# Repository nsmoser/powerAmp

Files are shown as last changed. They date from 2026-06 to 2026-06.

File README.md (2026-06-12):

Audio amplifier project implementing the LM3886 audio power amplifier.
Originally intended to replace a busted board in a powered subwoofer, but designed to be reused as a L/R stereo amp.
NOTE: the mute circuit was incorrectly connected to ground instead of the negative rail. Current draw necessary to unmute cannot be achieved unless the switch is connected to the negative rail.
Realistically, not all three matching pairs of caps in the cap bank are necessary. Connect the mute switch to one of the negative rail through holes in the cap bank if the bank isn't fully populated.
The low voltage power components are also not necessary for function. They are there to power peripherals (indicator lights, add-on pre-filters or pre-amps, etc.)

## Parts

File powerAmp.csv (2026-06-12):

Reference | Qty | Value | DNP | Exclude from BOM | Exclude from Board | Footprint | Datasheet | PN
C1,C2 | 2 | 4.7u |  |  |  | Capacitor_SMD:C_0805_2012Metric | ~ | GRM21BZ71H475ME15K
C3,C4,C9,C12 | 4 | 0.1u |  |  |  | Capacitor_SMD:C_1206_3216Metric | ~ | CL31B104KEHSFNE
C5,C6,C7,C8,C10,C11 | 6 | 10000u |  |  |  | Capacitor_THT:CP_Radial_D35.0mm_P10.00mm_SnapIn | ~ | EKMH500VSN103MA40U
C13 | 1 | .1u |  |  |  | Capacitor_SMD:C_0402_1005Metric | ~ | GCM155R71H104KE02J
C14,C15 | 2 | 10u |  |  |  | Capacitor_SMD:CP_Elec_5x5.3 | ~ | UCD1H100MCL6GS
D1,D2 | 2 | GBU8B |  |  |  | Diode_THT:Diode_Bridge_Vishay_GBU | http://www.vishay.com/docs/88656/gbu8a.pdf | GBU8B
D3 | 1 | LED |  |  |  | Connector_PinSocket_2.54mm:PinSocket_1x02_P2.54mm_Vertical | ~
FL1,FL2 | 2 | Choke_Schaffner_RN102-2-02-1M1 |  |  |  | Inductor_THT:Choke_Schaffner_RN102-04-14.0x14.0mm | https://www.schaffner.com/products/download/product/datasheet/rn-series-common-mode-chokes-new/ | RN102-2-02-1M1
H1,H2,H3,H4 | 4 | MountingHole_Pad |  | Excluded from BOM |  | MountingHole:MountingHole_4.3mm_M4_Pad_TopBottom | ~
J1 | 1 | Conn_Coaxial_x2 |  |  |  | Connector_PinSocket_2.54mm:PinSocket_1x03_P2.54mm_Vertical | ~
J2 | 1 | Conn_01x05 |  |  |  | Connector_PinSocket_2.54mm:PinSocket_1x05_P2.54mm_Vertical | ~
J3 | 1 | Conn_01x02_Pin |  |  |  | Connector_PinSocket_2.54mm:PinSocket_1x02_P2.54mm_Vertical | ~
J4,J5,J6,J7 | 4 | Conn_01x01_Socket |  |  |  | Connector_PinSocket_2.54mm:PinSocket_1x01_P2.54mm_Vertical | ~
R1,R2 | 2 | 1M |  |  |  | Resistor_SMD:R_2512_6332Metric | ~ | CHV2512-FX-1004ELF
R3 | 1 | 1500 |  |  |  | Resistor_SMD:R_0603_1608Metric | ~ | CRCW06031K50FKEAC
RV1,RV2 | 2 | levelCal |  |  |  | Potentiometer_THT:Potentiometer_Bourns_3009P_Horizontal | ~ | 3009P-1-104LF
RV3,RV4 | 2 | volAdjust |  |  |  | Connector_PinSocket_2.54mm:PinSocket_1x03_P2.54mm_Vertical | ~ | PDB181-E420F-103B1
SW1 | 1 | SW_SPST |  |  |  | Connector_PinSocket_2.54mm:PinSocket_1x02_P2.54mm_Vertical | ~
TP1 | 1 | in_preCal_L |  |  |  | TestPoint:TestPoint_Pad_1.0x1.0mm | ~
TP2 | 1 | in_preCal_R |  |  |  | TestPoint:TestPoint_Pad_1.0x1.0mm | ~
TP3 | 1 | in_postCal_L+ |  |  |  | Connector_PinHeader_2.54mm:PinHeader_1x01_P2.54mm_Vertical | ~
TP4 | 1 | in_postCal_R+ |  |  |  | Connector_PinHeader_2.54mm:PinHeader_1x01_P2.54mm_Vertical | ~
TP5 | 1 | in_postCal_L- |  |  |  | Connector_PinHeader_2.54mm:PinHeader_1x01_P2.54mm_Vertical | ~
TP6 | 1 | in_postCal_R- |  |  |  | Connector_PinHeader_2.54mm:PinHeader_1x01_P2.54mm_Vertical | ~
TP7 | 1 | dc- |  |  |  | TestPoint:TestPoint_Pad_1.0x1.0mm | ~
TP8 | 1 | gnd |  |  |  | TestPoint:TestPoint_Pad_1.0x1.0mm | ~
TP9 | 1 | dc+ |  |  |  | TestPoint:TestPoint_Pad_1.0x1.0mm | ~
TP10 | 1 | amp_in_L |  |  |  | Connector_PinHeader_2.54mm:PinHeader_1x01_P2.54mm_Vertical | ~
TP11 | 1 | amp_in_R |  |  |  | Connector_PinHeader_2.54mm:PinHeader_1x01_P2.54mm_Vertical | ~
U1 | 1 | LM7812_TO220 |  |  |  | Package_TO_SOT_THT:TO-220-3_Vertical | https://www.onsemi.cn/PowerSolutions/document/MC7800-D.PDF

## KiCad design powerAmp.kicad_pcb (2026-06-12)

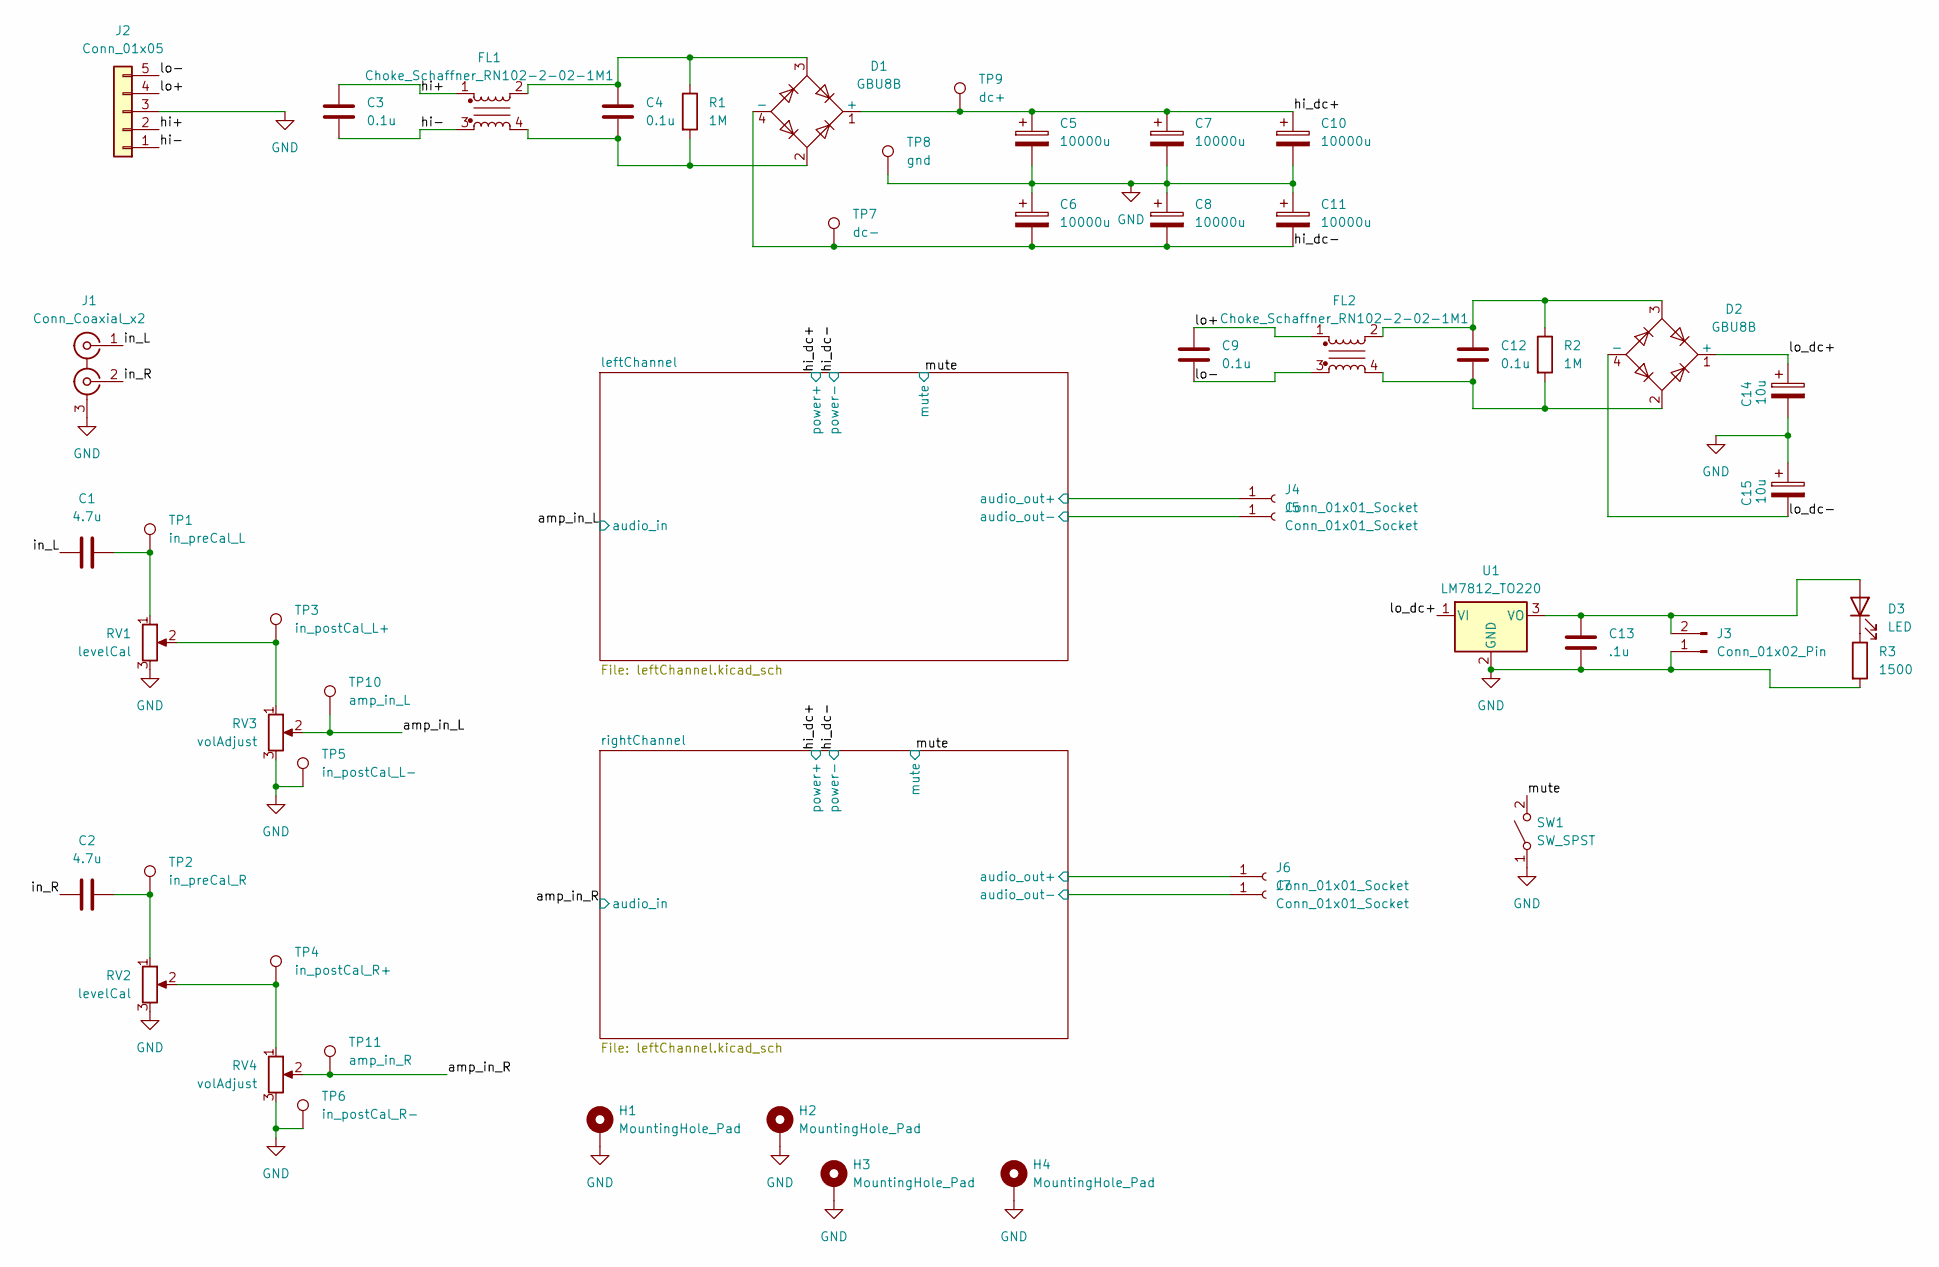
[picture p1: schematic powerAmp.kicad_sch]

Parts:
C1, C2: 4.7u; C_0805_2012Metric
C3, C4, C9, C12: 0.1u; C_1206_3216Metric
C5, C6, C7, C8, C10, C11: 10000u; CP_Radial_D35.0mm_P10.00mm_SnapIn
C13: .1u; C_0402_1005Metric
C14, C15: 10u; CP_Elec_5x5.3
D1, D2: GBU8B; Diode_Bridge_Vishay_GBU
D3: LED; PinSocket_1x02_P2.54mm_Vertical
FL1, FL2: Choke_Schaffner_RN102-2-02-1M1; Choke_Schaffner_RN102-04-14.0x14.0mm
H1, H2, H3, H4: MountingHole_Pad; MountingHole_4.3mm_M4_Pad_TopBottom
J1: Conn_Coaxial_x2; PinSocket_1x03_P2.54mm_Vertical
J2: Conn_01x05; PinSocket_1x05_P2.54mm_Vertical
J3: Conn_01x02_Pin; PinSocket_1x02_P2.54mm_Vertical
J4, J5, J6, J7: Conn_01x01_Socket; PinSocket_1x01_P2.54mm_Vertical
R1, R2: 1M; R_2512_6332Metric
R3: 1500; R_0603_1608Metric
RV1, RV2: levelCal; Potentiometer_Bourns_3009P_Horizontal
RV3, RV4: volAdjust; PinSocket_1x03_P2.54mm_Vertical
SW1: SW_SPST; PinSocket_1x02_P2.54mm_Vertical
TP1: in_preCal_L; TestPoint_Pad_1.0x1.0mm
TP2: in_preCal_R; TestPoint_Pad_1.0x1.0mm
TP3: in_postCal_L+; PinHeader_1x01_P2.54mm_Vertical
TP4: in_postCal_R+; PinHeader_1x01_P2.54mm_Vertical
TP5: in_postCal_L-; PinHeader_1x01_P2.54mm_Vertical
TP6: in_postCal_R-; PinHeader_1x01_P2.54mm_Vertical
TP7: dc-; TestPoint_Pad_1.0x1.0mm
TP8: gnd; TestPoint_Pad_1.0x1.0mm
TP9: dc+; TestPoint_Pad_1.0x1.0mm
TP10: amp_in_L; PinHeader_1x01_P2.54mm_Vertical
TP11: amp_in_R; PinHeader_1x01_P2.54mm_Vertical
U1: LM7812_TO220; TO-220-3_Vertical

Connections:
/amp_in_L: RV3.2, TP10.1; also elsewhere on the board
/amp_in_R: RV4.2, TP11.1; also elsewhere on the board
/hi+: C3.1, FL1.1, J2.2
/hi-: C3.2, FL1.3, J2.1
/hi_dc+: C5.1, C7.1, C10.1, D1.1 (+), TP9.1; also elsewhere on the board
/hi_dc-: C6.2, C8.2, C11.2, D1.4 (-), TP7.1; also elsewhere on the board
/in_L: C1.1, J1.1 (IN1)
/in_R: C2.1, J1.2 (IN2)
/leftChannel/audio_out+: J4.1; also elsewhere on the board
/leftChannel/audio_out-: J5.1; also elsewhere on the board
/lo+: C9.1, FL2.1, J2.4
/lo-: C9.2, FL2.3, J2.5
/lo_dc+: C14.1, D2.1 (+), U1.1 (VI)
/lo_dc-: C15.2, D2.4 (-)
/mute: SW1.2 (B); also elsewhere on the board
/rightChannel/audio_out+: J6.1; also elsewhere on the board
/rightChannel/audio_out-: J7.1; also elsewhere on the board
GND: C5.2, C6.1, C7.2, C8.1, C10.2, C11.1, C13.1, C14.2, C15.1, H1.1, H2.1, H3.1, H4.1, J1.3 (EXT), J2.3, J3.1, R3.2, RV1.3, RV2.3, RV3.3, RV4.3, SW1.1 (A), TP5.1, TP6.1, TP8.1, U1.2 (GND); also elsewhere on the board
unnamed: C1.2, RV1.1, TP1.1
unnamed: C2.2, RV2.1, TP2.1
unnamed: C4.1, D1.3, FL1.2, R1.1
unnamed: C4.2, D1.2, FL1.4, R1.2
unnamed: C12.1, D2.3, FL2.2, R2.1
unnamed: C12.2, D2.2, FL2.4, R2.2
unnamed: C13.2, D3.2 (A), J3.2, U1.3 (VO)
unnamed: D3.1 (K), R3.1
unnamed: RV1.2, RV3.1, TP3.1
unnamed: RV2.2, RV4.1, TP4.1

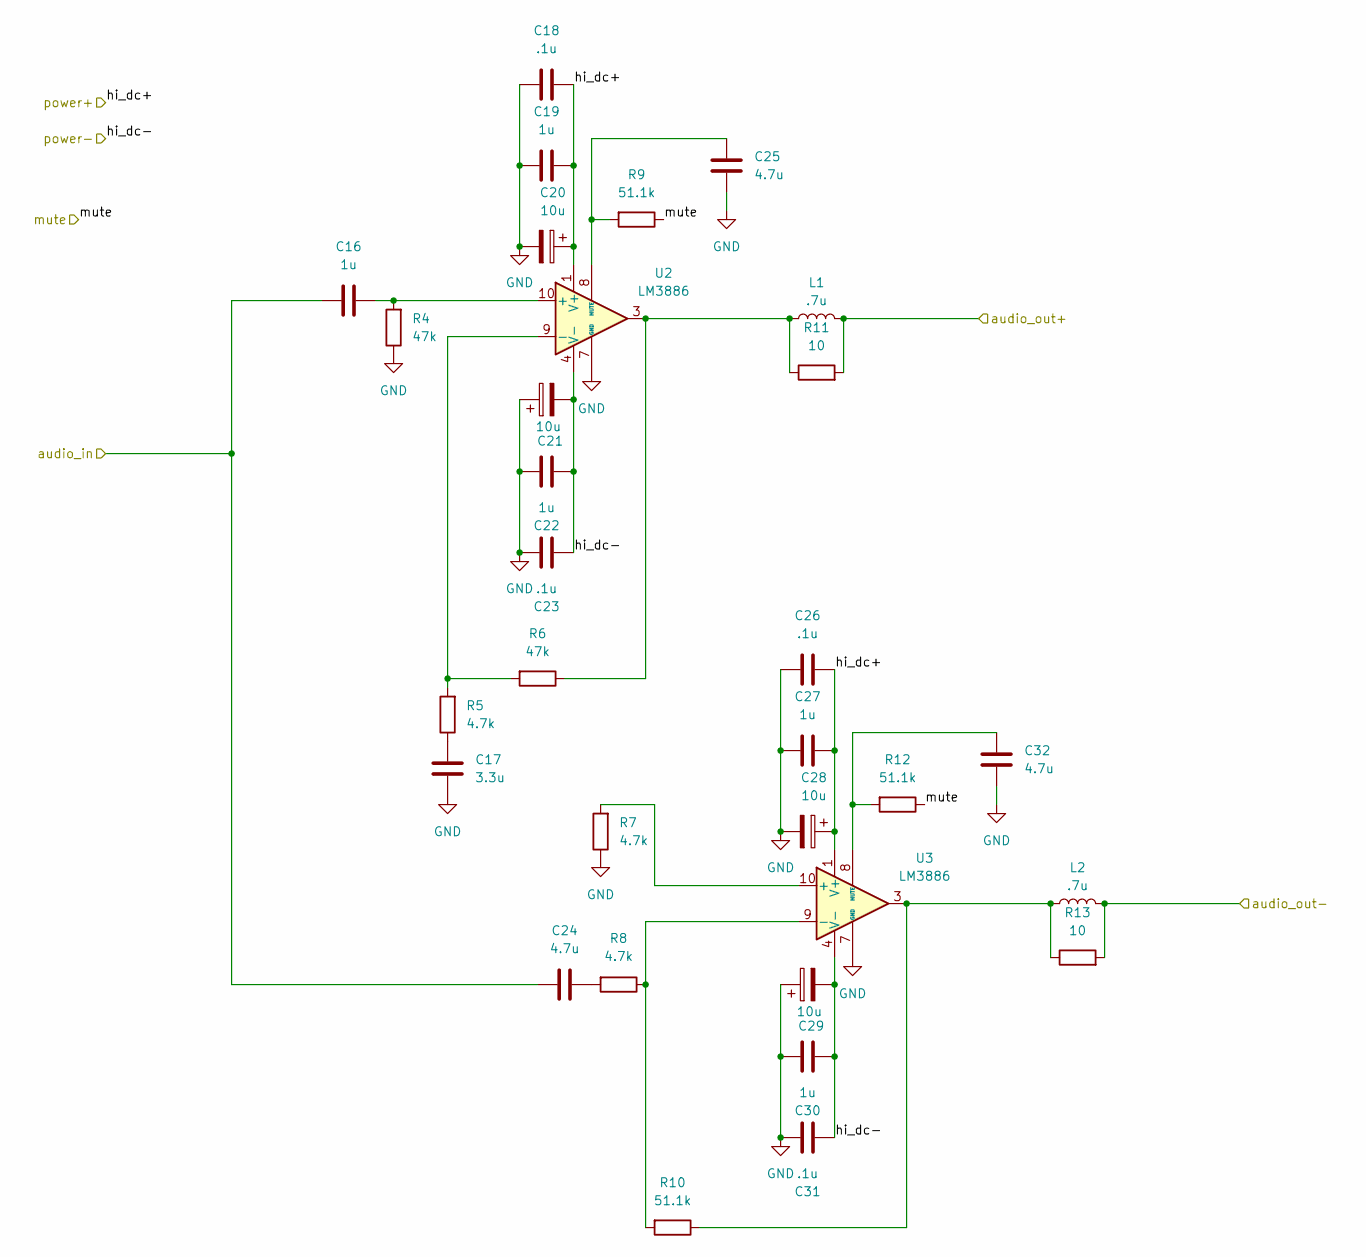
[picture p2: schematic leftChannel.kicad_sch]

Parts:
C16, C19, C22, C27, C30: 1u; C_0805_2012Metric
C17: 3.3u; C_1210_3225Metric
C18, C23, C26, C31: .1u; C_0402_1005Metric
C20, C21, C28, C29: 10u; CP_Elec_5x5.3
C24, C25, C32: 4.7u; C_0805_2012Metric
L1, L2: .7u; L_Vishay_IHLP-1616
R4, R6: 47k; R_0603_1608Metric
R5, R7, R8: 4.7k; R_0603_1608Metric
R9, R10, R12: 51.1k; R_0603_1608Metric
R11, R13: 10; PinSocket_1x02_P2.54mm_Vertical
U2, U3: LM3886; TO-220F-11_P3.4x5.08mm_StaggerOdd_Lead5.08mm_Vertical

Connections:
/amp_in_L: C16.1, C24.1; also elsewhere on the board
/hi_dc+: C18.2, C19.2, C20.1, C26.2, C27.2, C28.1, U2.1 (V+), U2.5 (V+), U3.1 (V+), U3.5 (V+); also elsewhere on the board
/hi_dc-: C21.2, C22.1, C23.1, C29.2, C30.1, C31.1, U2.4 (V-), U3.4 (V-); also elsewhere on the board
/leftChannel/audio_out+: L1.2, R11.2; also elsewhere on the board
/leftChannel/audio_out-: L2.2, R13.2; also elsewhere on the board
/mute: R9.1, R12.1; also elsewhere on the board
GND: C17.1, C18.1, C19.1, C20.2, C21.1, C22.2, C23.2, C25.1, C26.1, C27.1, C28.2, C29.1, C30.2, C31.2, C32.1, R4.1, R7.1, U2.7 (GND), U3.7 (GND); also elsewhere on the board
unnamed: C17.2, R5.1
unnamed: C24.2, R8.2
unnamed: L1.1, R6.1, R11.1, U2.3
unnamed: L2.1, R10.1, R13.1, U3.3
unnamed: C16.2, R4.2, U2.10 (+)
unnamed: R5.2, R6.2, U2.9 (-)
unnamed: C25.2, R9.2, U2.8 (MUTE)
unnamed: R7.2, U3.10 (+)
unnamed: R8.1, R10.2, U3.9 (-)
unnamed: C32.2, R12.2, U3.8 (MUTE)

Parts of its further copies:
C33, C36, C39, C44, C47: 1u; C_0805_2012Metric
C34: 3.3u; C_1210_3225Metric
C35, C40, C43, C48: .1u; C_0402_1005Metric
C37, C38, C45, C46: 10u; CP_Elec_5x5.3
C41, C42, C49: 4.7u; C_0805_2012Metric
L3, L4: .7u; L_Vishay_IHLP-1616
R14, R16: 47k; R_0603_1608Metric
R15, R17, R18: 4.7k; R_0603_1608Metric
R19, R20, R22: 51.1k; R_0603_1608Metric
R21, R23: 10; PinSocket_1x02_P2.54mm_Vertical
U4, U5: LM3886; TO-220F-11_P3.4x5.08mm_StaggerOdd_Lead5.08mm_Vertical

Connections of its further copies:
/amp_in_R: C33.1, C41.1; also elsewhere on the board
/hi_dc+: C35.2, C36.2, C37.1, C43.2, C44.2, C45.1, U4.1 (V+), U4.5 (V+), U5.1 (V+), U5.5 (V+); also elsewhere on the board
/hi_dc-: C38.2, C39.1, C40.1, C46.2, C47.1, C48.1, U4.4 (V-), U5.4 (V-); also elsewhere on the board
/mute: R19.1, R22.1; also elsewhere on the board
/rightChannel/audio_out+: L3.2, R21.2; also elsewhere on the board
/rightChannel/audio_out-: L4.2, R23.2; also elsewhere on the board
GND: C34.1, C35.1, C36.1, C37.2, C38.1, C39.2, C40.2, C42.1, C43.1, C44.1, C45.2, C46.1, C47.2, C48.2, C49.1, R14.1, R17.1, U4.7 (GND), U5.7 (GND); also elsewhere on the board
unnamed: C34.2, R15.1
unnamed: C41.2, R18.2
unnamed: L3.1, R16.1, R21.1, U4.3
unnamed: L4.1, R20.1, R23.1, U5.3
unnamed: C33.2, R14.2, U4.10 (+)
unnamed: R15.2, R16.2, U4.9 (-)
unnamed: C42.2, R19.2, U4.8 (MUTE)
unnamed: R17.2, U5.10 (+)
unnamed: R18.1, R20.2, U5.9 (-)
unnamed: C49.2, R22.2, U5.8 (MUTE)

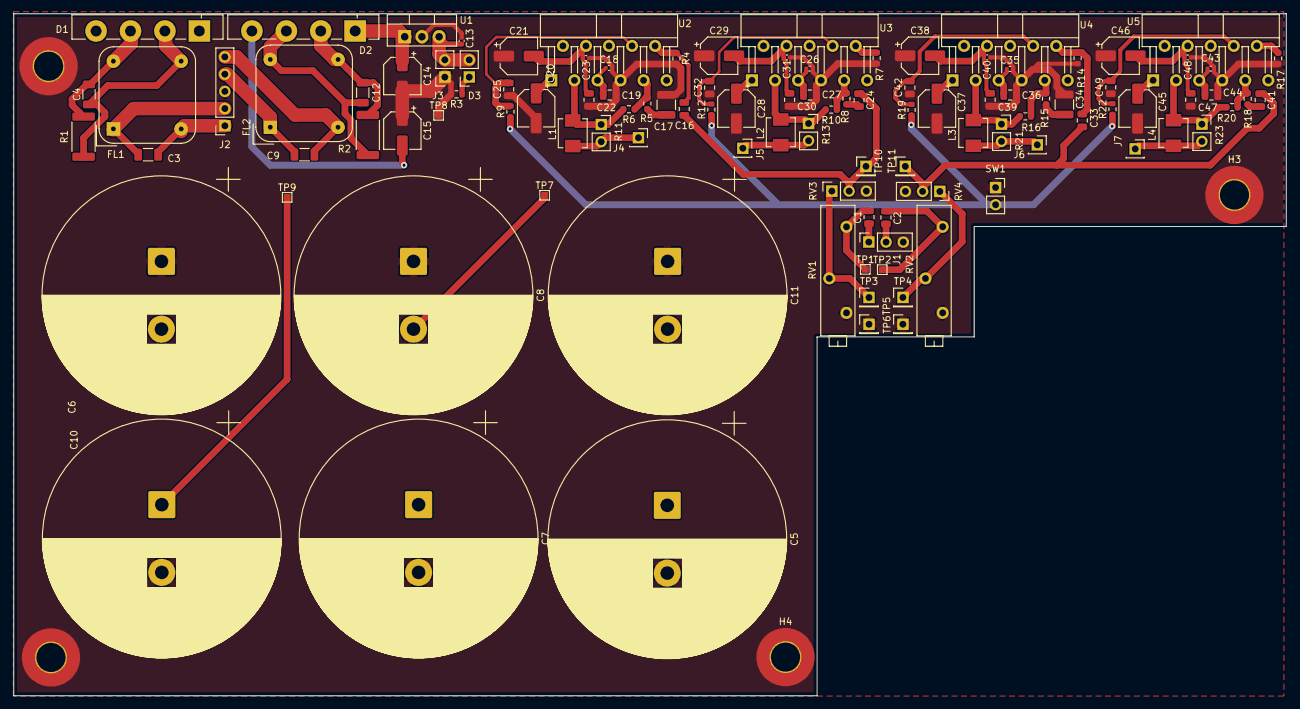
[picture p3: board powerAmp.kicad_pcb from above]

Board: 6 copper layers, 187.8 x 100.6 mm, 113 parts (0 on the bottom side), 48 nets.
